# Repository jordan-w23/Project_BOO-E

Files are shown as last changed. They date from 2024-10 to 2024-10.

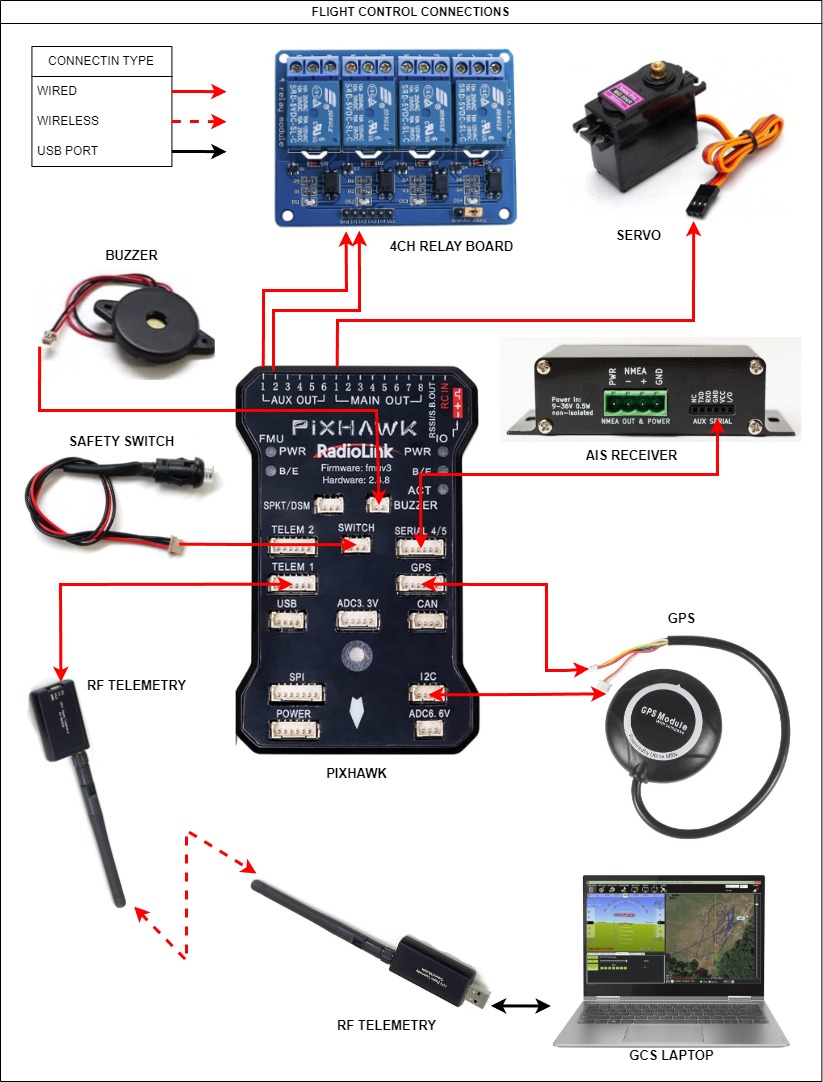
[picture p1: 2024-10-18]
BOO-E Diagrams/BOO-E overview-Signal and control flow.jpg

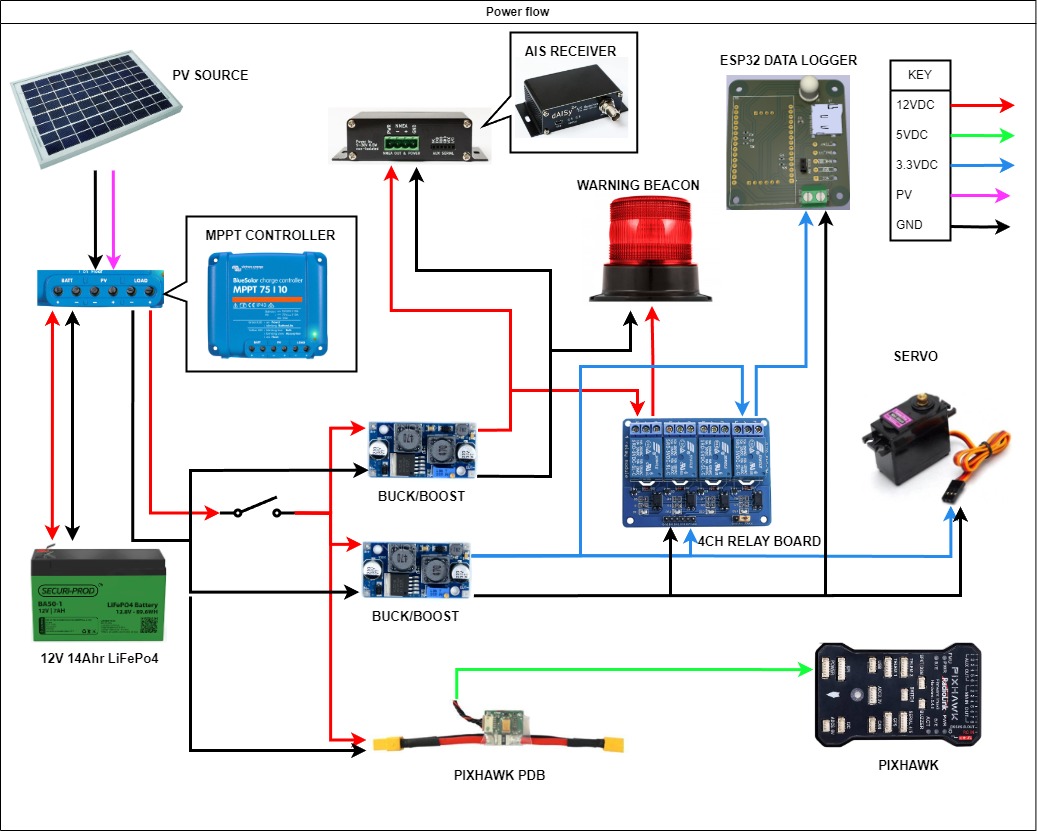
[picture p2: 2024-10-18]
BOO-E Diagrams/BOO-E overview-Power flow.jpg

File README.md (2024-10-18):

# Project_BOO-E
This is my Industrial designs project 3 for my 3rd year of Electrical Engineering studies. It is a proof of concept for a low cost autonomous vehicle using open-source recourses.
The system is broken down into 3 subsystems: Power, Navigation, Data logging
Ardupilot online forum is a key tool to use when setting up the flight controller and ground control station as most issues can be solved with a bit of research.

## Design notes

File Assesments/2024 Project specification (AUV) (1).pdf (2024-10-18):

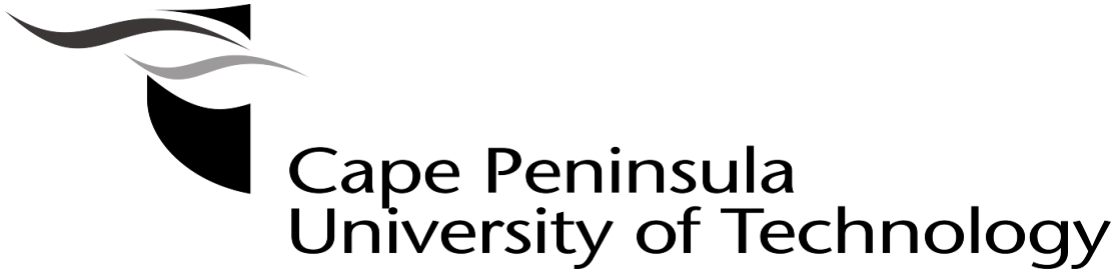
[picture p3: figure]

Title of project: Open-source based AUV

Problem Statement | The ocean is linked to weather, climate patterns, and all life on land. Thus, studying it helps researchers to predict trends and track the impact humans have made on the planet as well as monitor carbon emission levels. CTDs, moorings, gliders, and AUVs play a key role in data collection. However, these often require millions of rands to buy, thus excluding underfunded researchers from having access to ocean surveying and data collection instruments. Open-sourced designs allow for individuals to collaborate on projects, often resulting in higher quality, lower costs, and creates a positive space for growth and development within the project fields. Thus, there is a need for improvement and contributions towards open- source based AUV and glider projects.
Objectives | • Integrate various open-sourced components and software to develop a low cost AUV navigation system. • Integrate a source of regenerative energy and battery monitoring system. • Collect and log data from various sensors • Improve on electrical system to reduce power demand
Key Results | • Navigate via waypoint following • Long term deployment • Remote monitoring • Autonomous surfacing for recharging • Dive profile control
Impact/ Industry related significance | • Underfunded researchers have the means to conduct their own research at a fraction of the cost. • Open-source projects allows for goal specific modifications. • A positive contribution to the open-source community. • Accelerated innovation and development of more reliable, flexible and adaptable implementations

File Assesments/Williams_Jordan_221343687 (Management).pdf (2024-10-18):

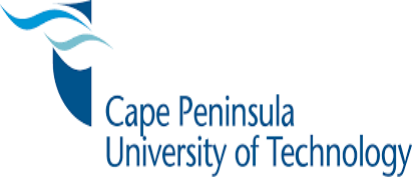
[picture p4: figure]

# Industrial Design Project 3 DES370S

## Project Title: Blue OpenOcean Explorer (BOO-E) Subtitle: Project Management Presentation

# Student Initial and Surname: JF Williams Student Number: 221343687 Lecturer: Dr M. Mnguni Date of Evaluation: 23/05/2024

23/05/2024 | 1

# Outline

## - Introduction • Proposed Plan • System overview • Benefits of Open

## -source Technology

- Budget Management • Risk Analysis • Time and Change Management • Quality Assurance • Economics Principles • Evaluation of Project Outcomes • Conclusion

23/05/2024

2

# Introduction

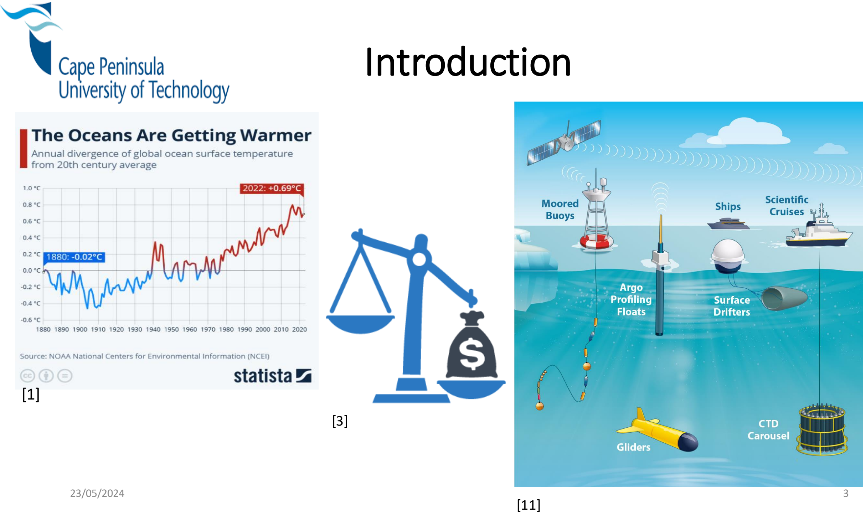
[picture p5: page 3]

[1]

[3]

[11]

# Proposed Plan Blue OpenOcean Explorer (BOO-E)

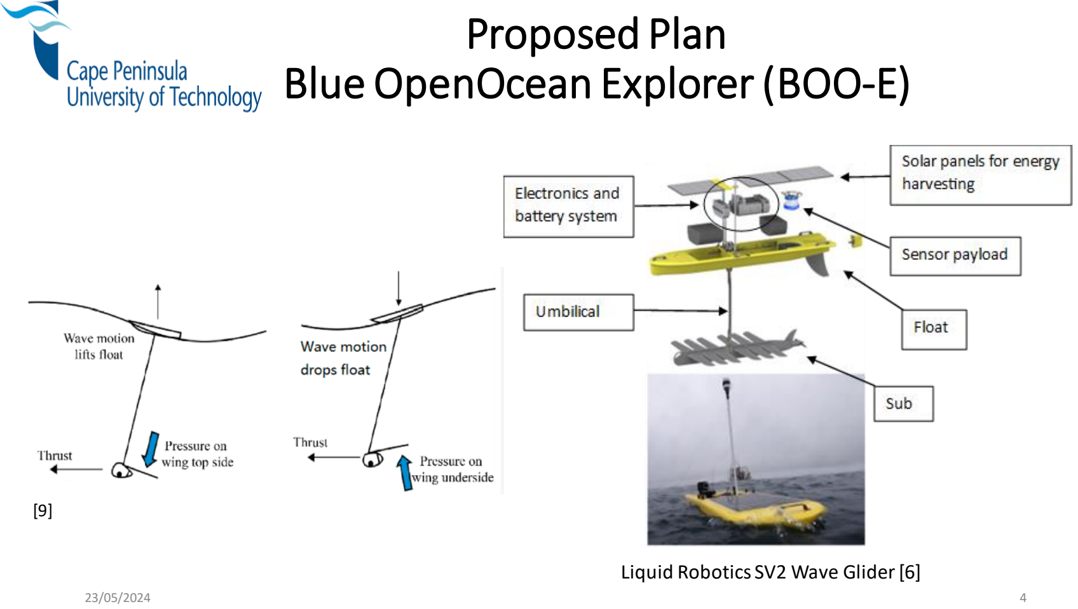
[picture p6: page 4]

### Liquid Robotics SV2 Wave Glider [6]

[9]

### Open-source based ASV project

### Navigation

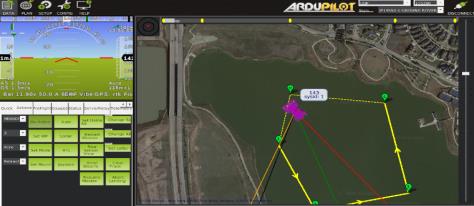
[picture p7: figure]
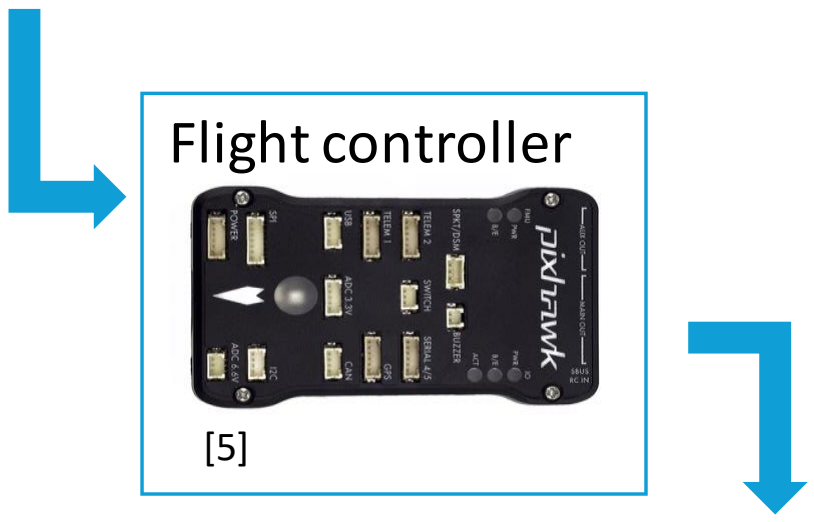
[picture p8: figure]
Flight controller

### Outputs: Rudder angle Thruster control Sail angle

### Inputs: GPS, Compass, IMU, Pilot control

### Data collection

### Sensors: Temp

### Salinity

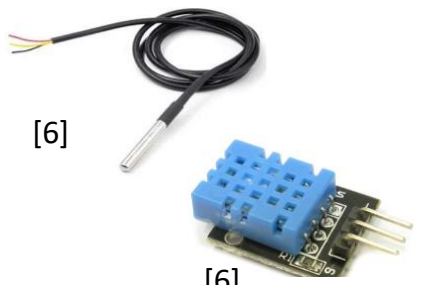
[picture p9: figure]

### Atmospheric data

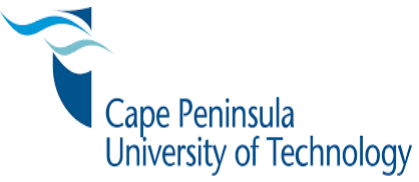
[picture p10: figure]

### Power management

### Harvesting: Solar and battery

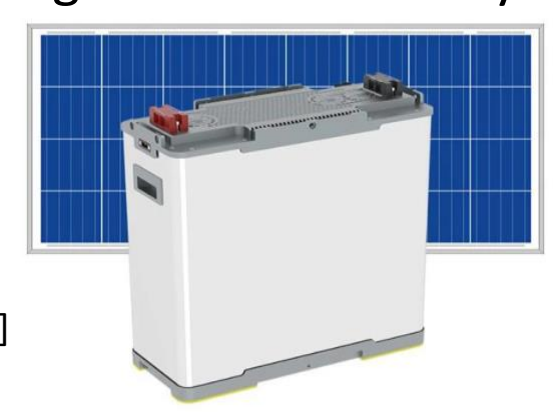
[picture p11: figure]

### storage

### Management: PDB's, DC-DC

# System overview

[5] [5]
[6]

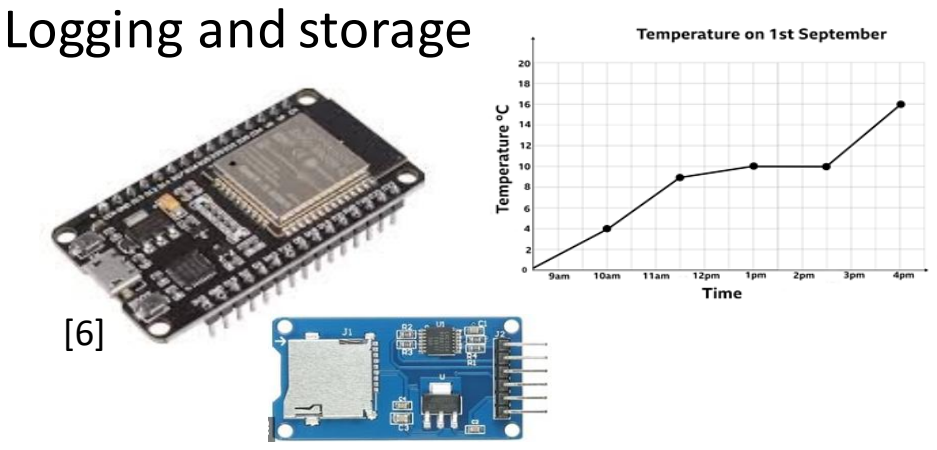
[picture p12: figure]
Logging and storage

[6]

[6]

[6]

# Benefits of Open-Source technology

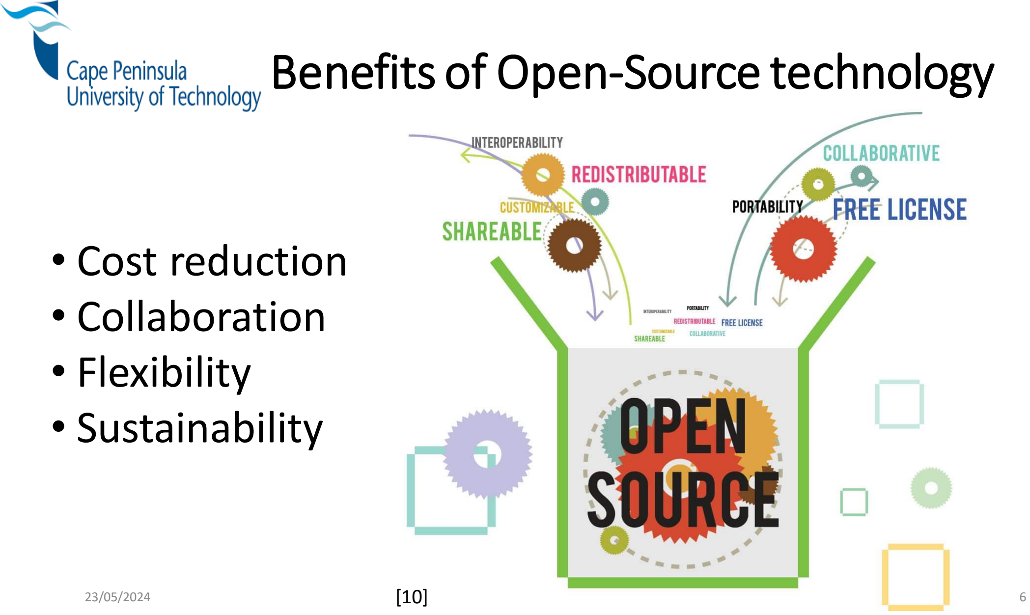
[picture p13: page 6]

# - Cost reduction - Collaboration - Flexibility - Sustainability

[10]

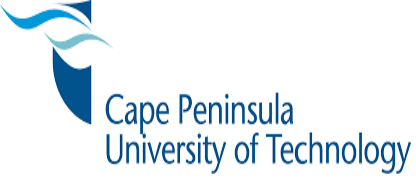
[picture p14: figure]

# Budget Management

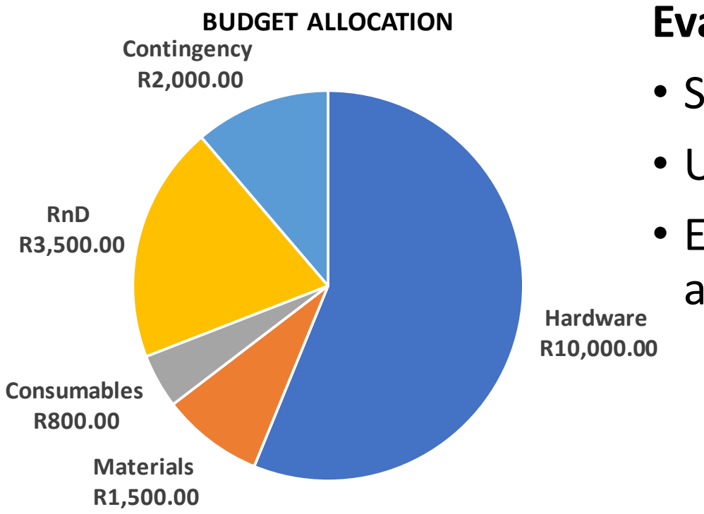
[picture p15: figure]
Hardware R10,000.00; Materials R1,500.00; Consumables R800.00; RnD R3,500.00; Contingency R2,000.00; BUDGET ALLOCATION

# Evaluation of Adherence to Budget - Securing sponsorships for companies (4, 7) - Use inhouse resources - Eliminate unnecessary expenses through risk assessment

### Budget total: R17,800.00

[4]

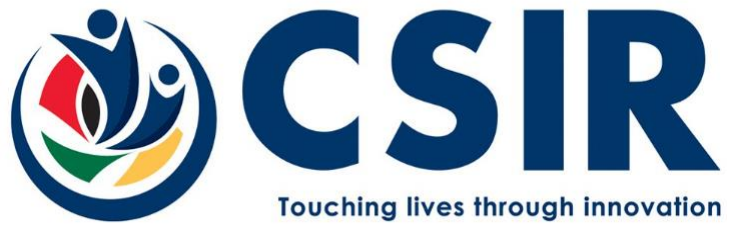
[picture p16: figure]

[7]

# Hardware cost breakdown

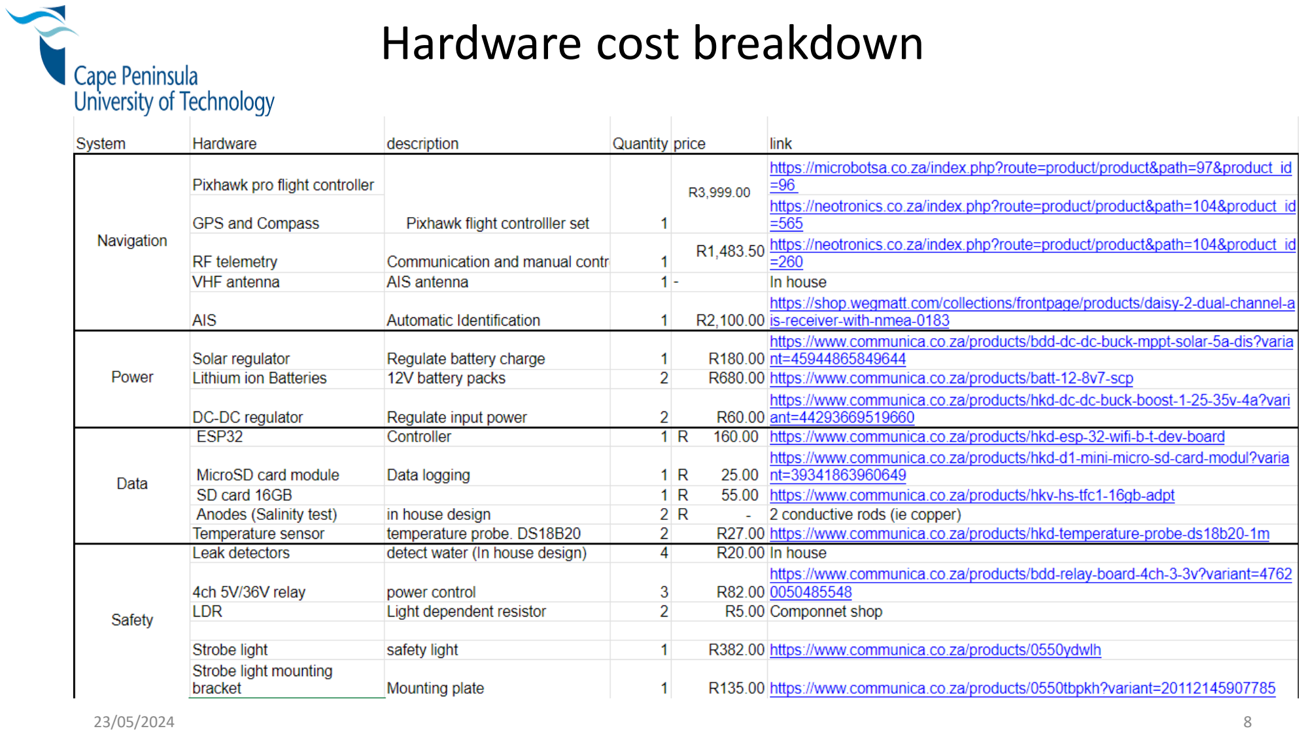
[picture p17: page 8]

# RISK ANALYSIS

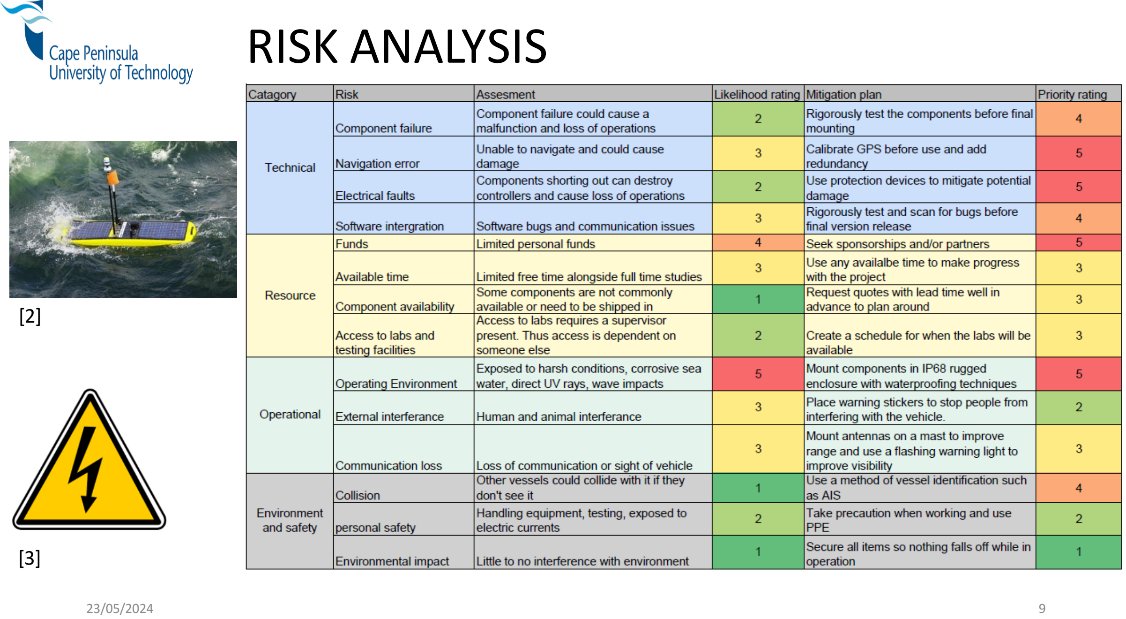
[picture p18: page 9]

[2]

[3]

# Time and Change Management

# - Monitoring Progress - Time Estimation for Each Task - Milestones and Deadlines

# Monitoring Progress

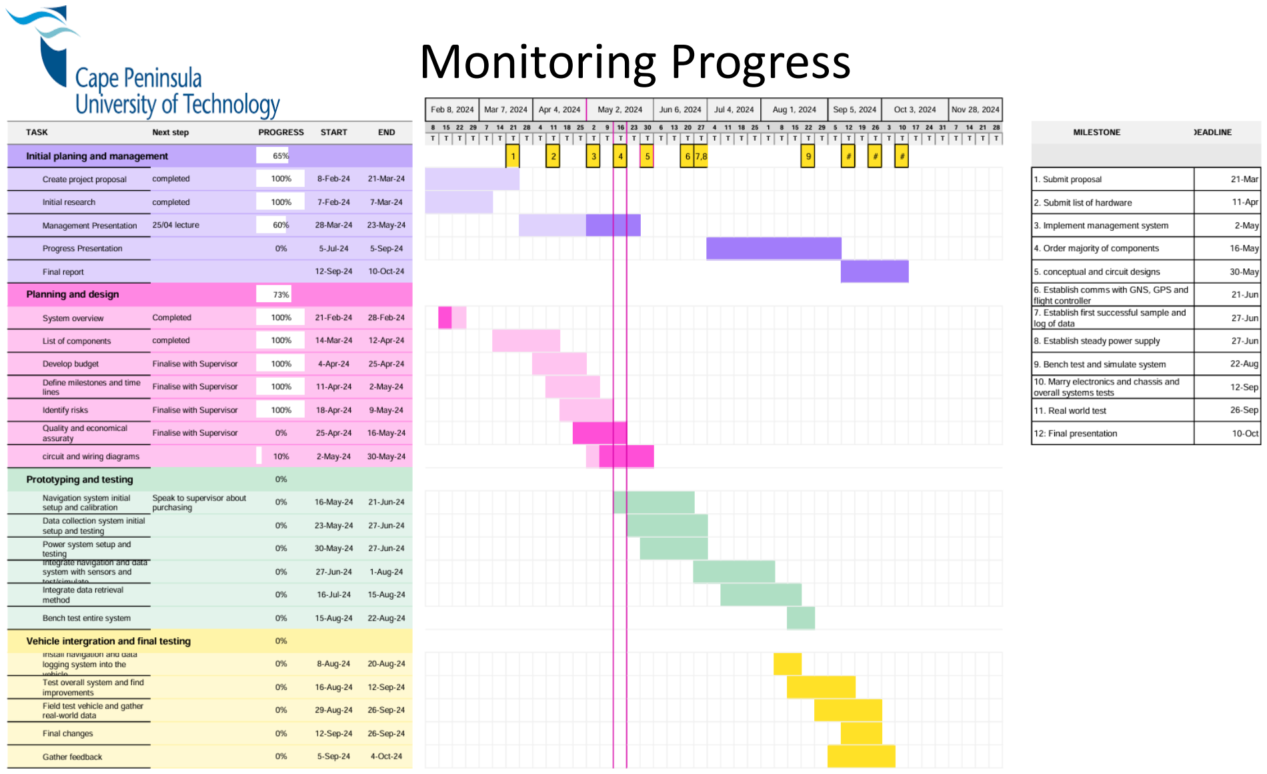
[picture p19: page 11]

# Time Estimation for Each Task

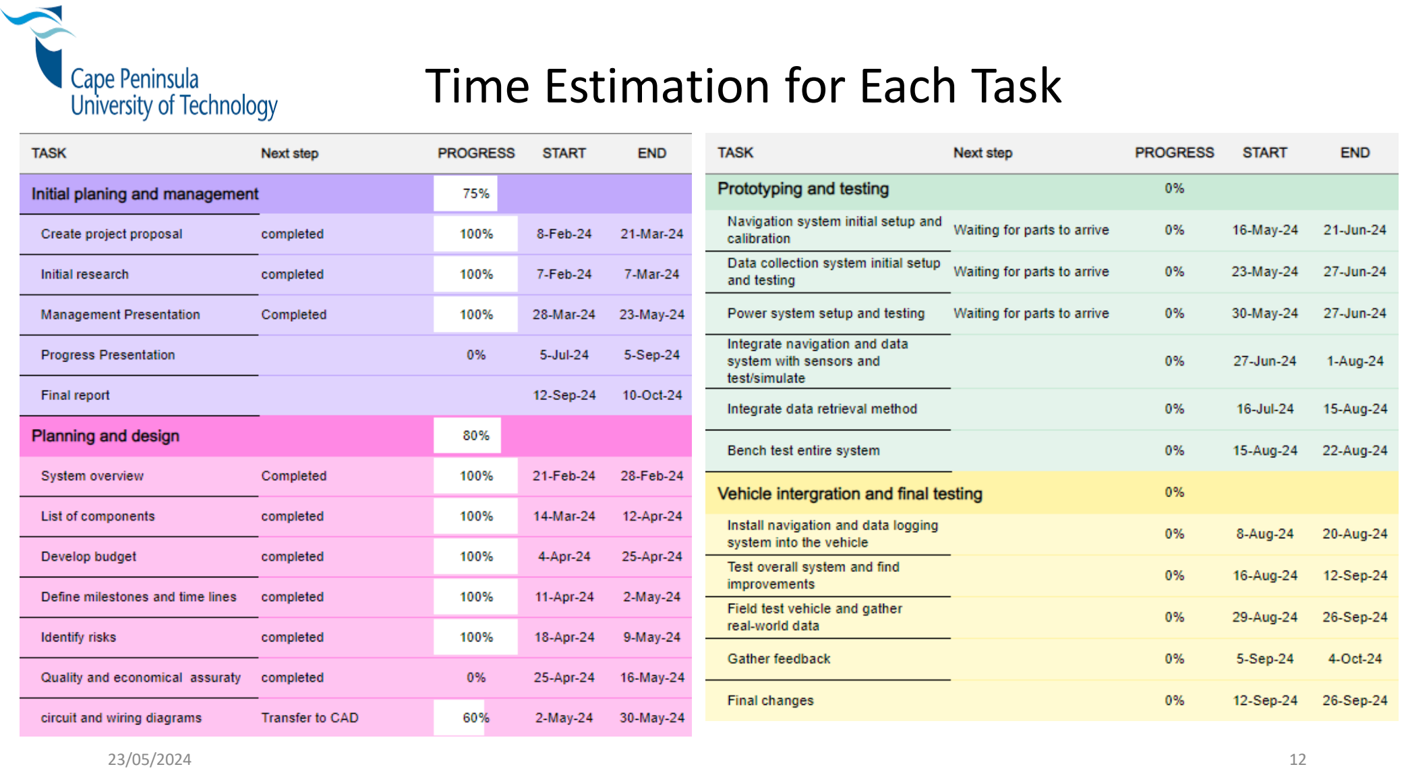
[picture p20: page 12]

# Milestones and deadlines

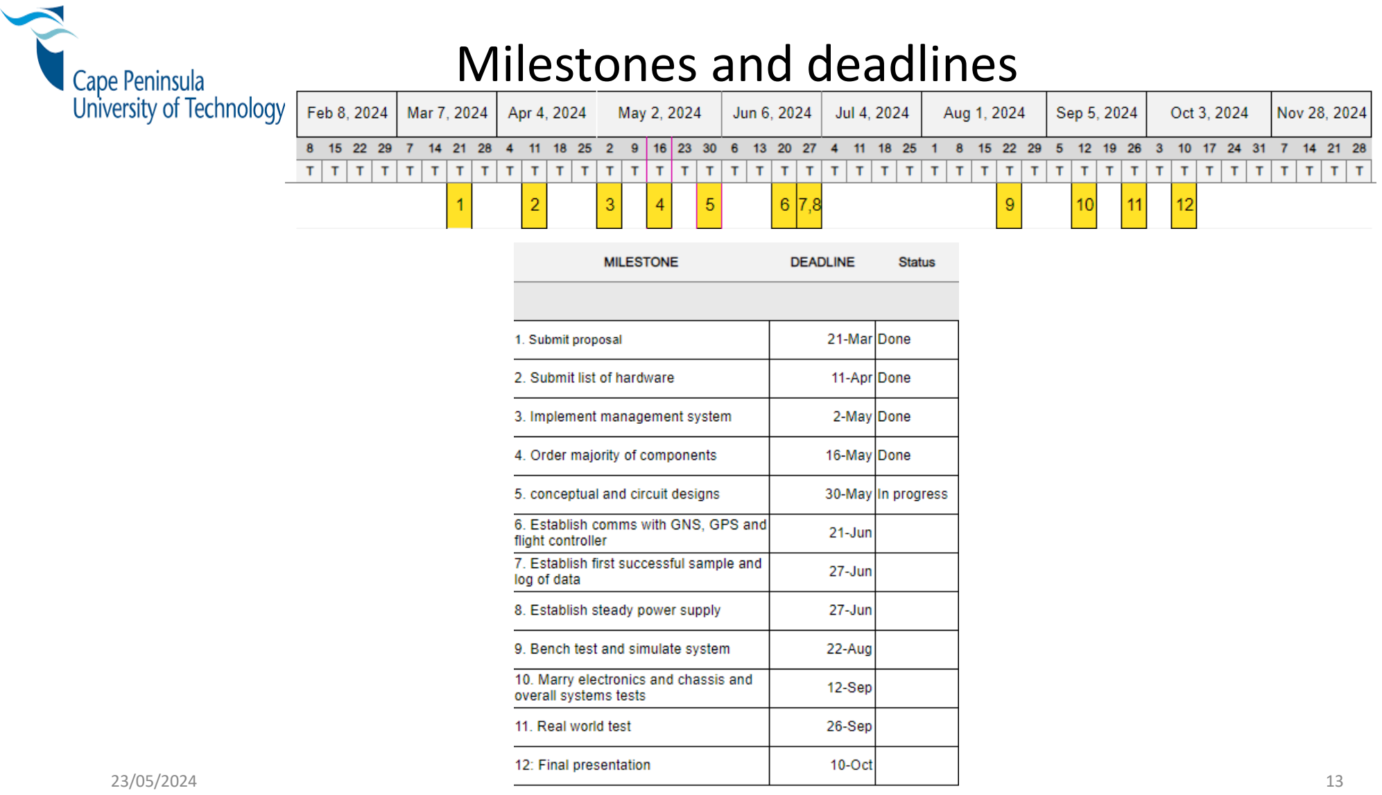
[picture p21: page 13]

# Quality Assurance

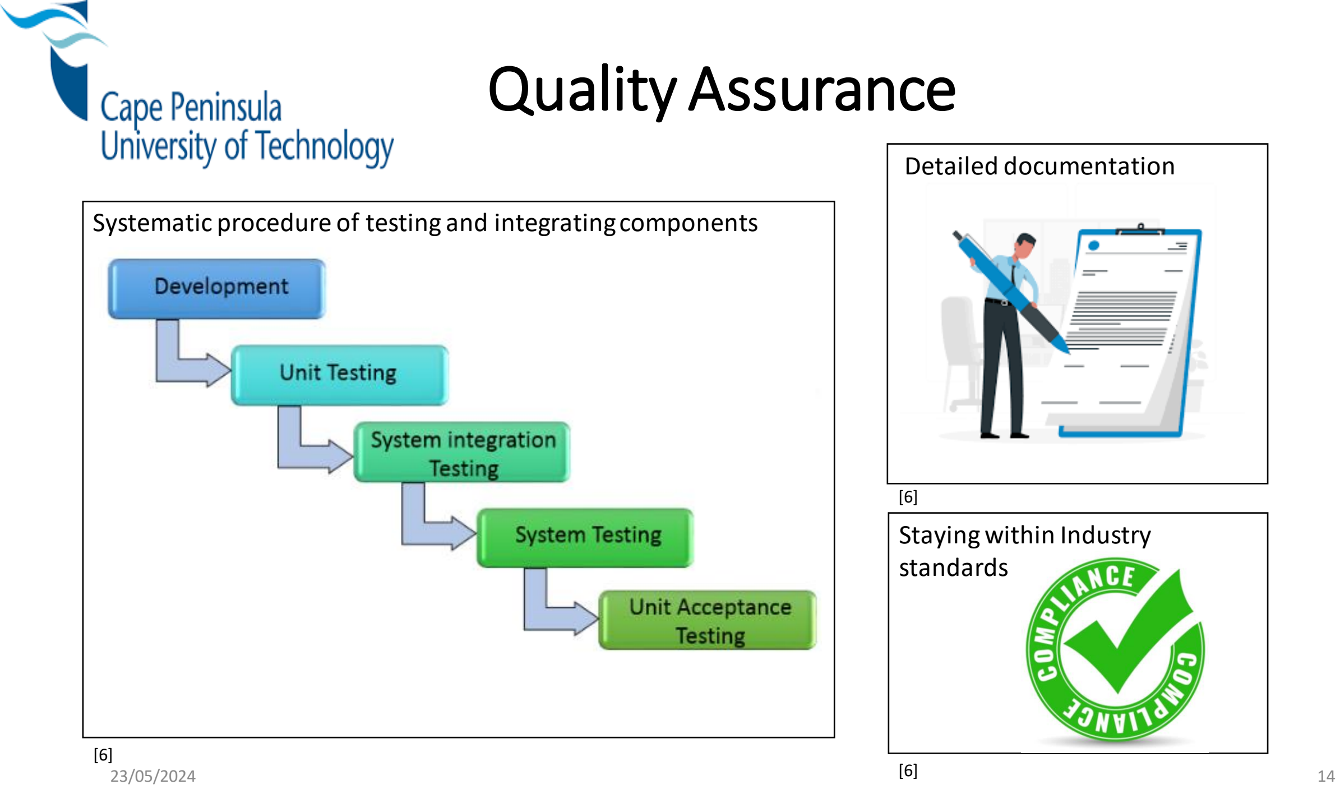
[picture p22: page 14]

### Systematic procedure of testing and integrating components

### Detailed documentation

### Staying within Industry standards

[6]
[6]

[6]

# Economics Principles

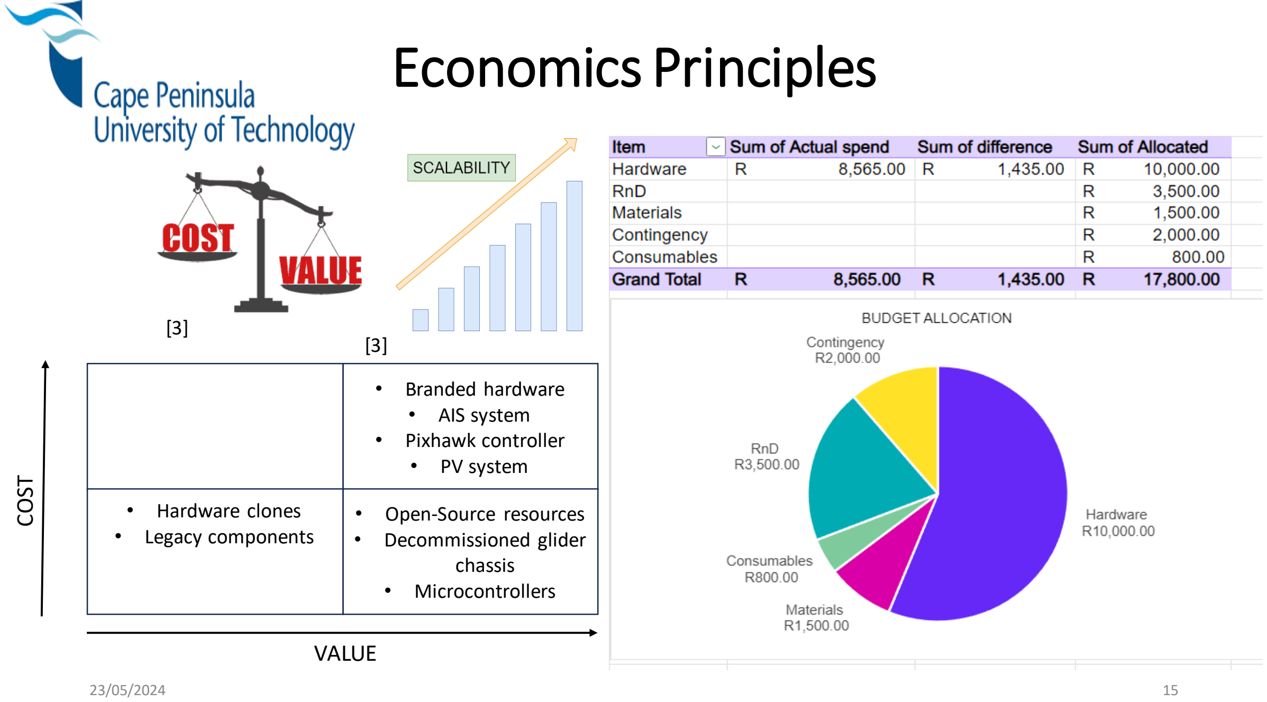
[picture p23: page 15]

| • Branded hardware • AIS system • Pixhawk controller • PV system
- Hardware clones • Legacy components | • Open-Source resources • Decommissioned glider chassis • Microcontrollers

### COST

### VALUE

[3]
[3]

# Expected Outcomes

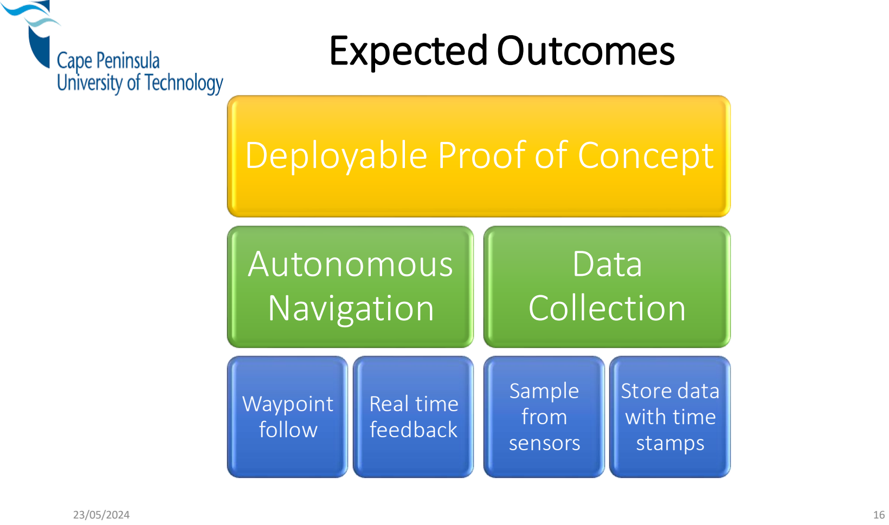
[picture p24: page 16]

# Deployable Proof of Concept

# Autonomous Navigation

## Waypoint follow

## Real time feedback

# Data Collection

## Sample from sensors

## Store data with time stamps

# Conclusion

# Proprietary < Open-Source

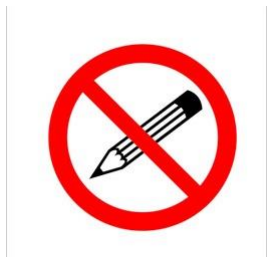
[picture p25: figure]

# - The more we understand the behaviour of our

oceans the better we can plan for our future.

[3] [3]

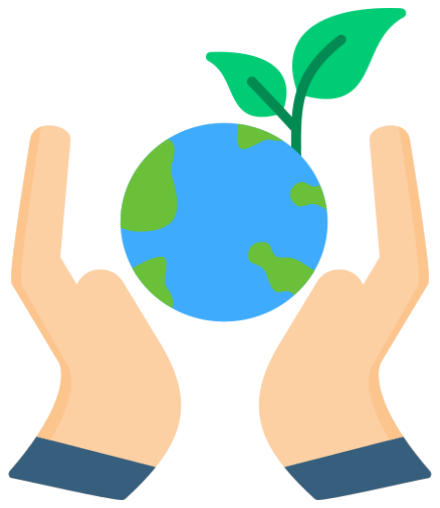
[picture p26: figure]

[3]

Thank you for you attention.

# Any questions?

## Contact details: Jordan Williams Cell: +27 78 136 7086 Email: 221343687@mycput.ac.za/ jordanwilliaams12@gmail.com


- [1] K. Buchholz, “Infographic: The Oceans Are Getting Warmer,” Statista Infographics, Jan. 15, 2021. https://www.statista.com/chart/19418/divergence-ofocean-temperatures-from-20th-century-average/ (https://www.statista.com/chart/19418/divergence-of-ocean-temperatures-from-20th-century-average/)
- [2] Sonardyne, “Redirect Notice,” Google.com, 2024. https://www.google.com/url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 AAAAAdAAAAABAE (https://www.google.com/url?psig=AOvVaw3xA_cL7y7ZwGIrjGevBaFK&cd=vfe&opi=89978449) (accessed May 21, 2024).
- [3] Clipart library , https://clipart-library.com/
- [4] Sea Technology Services, “Sea Technology Services,” Sea Technology Services. https://www.seatechnology.co.za/(accessed May 21, 2024).
- [5] Ardupilot, “Open Source Drone Software. Versatile, Trusted, Open. ArduPilot.,” ardupilot.org. https://ardupilot.org/
- [6] Communica south aftrica, “Communica South Africa,” Communica South Africa. https://www.communica.co.za/
- [7] “Council for Scientific and Industrial Research (CSIR) - Overview,” nationalgovernment.co.za. https://nationalgovernment.co.za/units/view/212/council-forscientific-and-industrial-research-csir (https://nationalgovernment.co.za/units/view/212/council-for-scientific-and-industrial-research-csir)
- [8] T. Morris et al., “Monitoring Boundary Currents Using Ocean Observing Infrastructure | Oceanography,” Frontiers in Ocean Observing: Documenting
Ecosystems, Understanding Environmental Changes, Forecasting Hazards, vol. 34, no. 4, Jan. 2022, doi: https://doi.org/10.5670/oceanog.2021..
- [9] X. Chen, M. Hong, S. Wu, K. Liu, and K. Mao, “Design of Wave Glider Optimal Parameters Suitable for the Northwest Pacific Ocean, the North Indian Ocean, and the South China Sea,” Journal of Marine Science and Engineering, vol. 9, no. 4, p. 408, Apr. 2021, doi: https://doi.org/10.3390/jmse9040408.
- [10] S. Kolhe, “The Benefits of Open Source Products,” opensourceforu, Sep. 20, 2015. https://www.opensourceforu.com/2015/09/the-benefits-of-open-source-products/?amp (accessed May 21, 2024).
- [11] Van Lancker and M. Baeye, “Wave Glider Monitoring of Sediment Transport and Dredge Plumes in a Shallow Marine Sandbank Environment,” PLOS ONE, vol. 10, no. 6, p. 5/15, Jun. 2015, doi: https://doi.org/10.1371/journal.pone.0128948.

# References

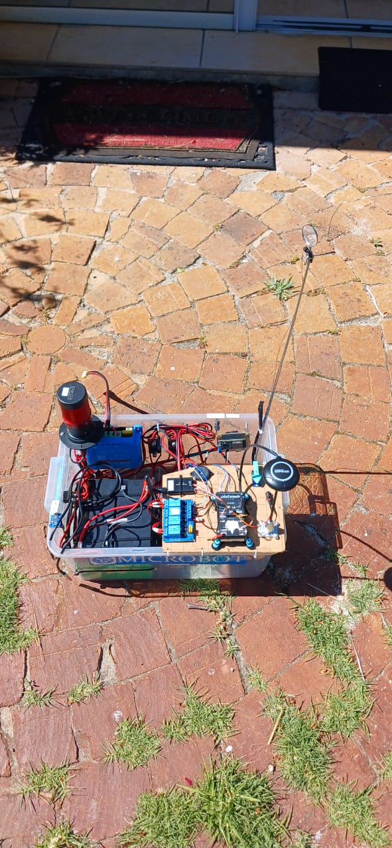
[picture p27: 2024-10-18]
Pictures/BOO-E/IMG-20241016-WA0004.jpg

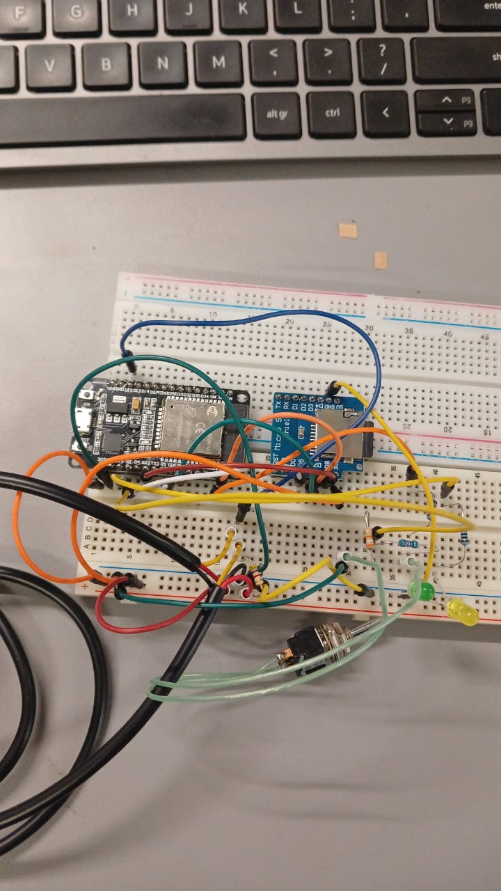
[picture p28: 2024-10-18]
Pictures/Data logger/IMG-20241016-WA0014.jpg

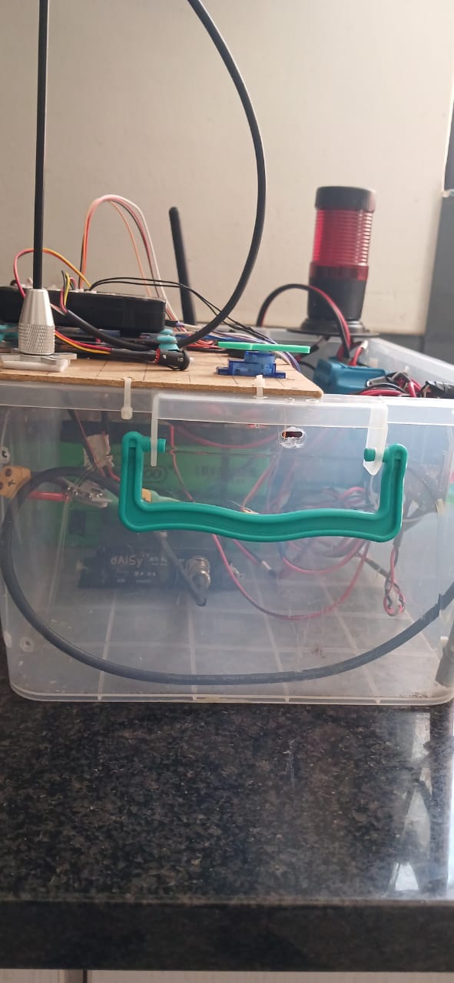
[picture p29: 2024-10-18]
Pictures/BOO-E/IMG-20241016-WA0055.jpg

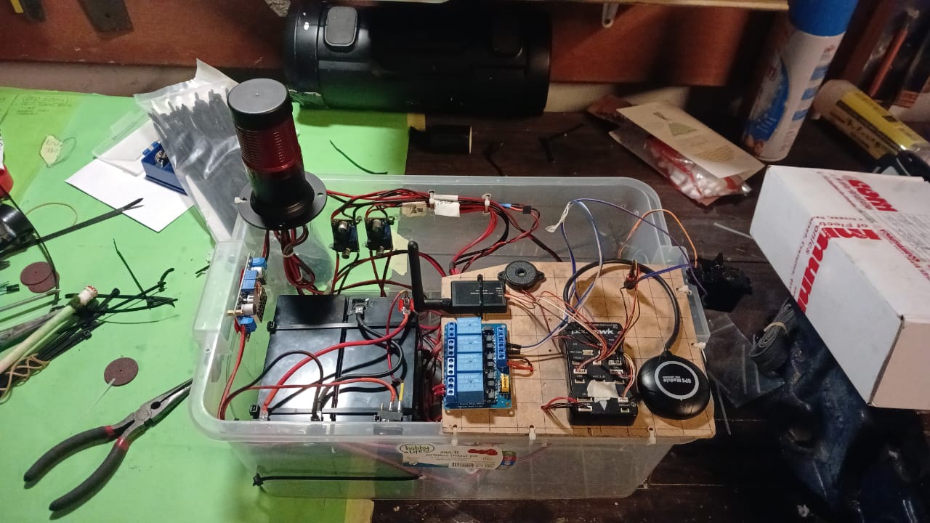
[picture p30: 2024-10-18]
Pictures/BOO-E/IMG-20241016-WA0012.jpg

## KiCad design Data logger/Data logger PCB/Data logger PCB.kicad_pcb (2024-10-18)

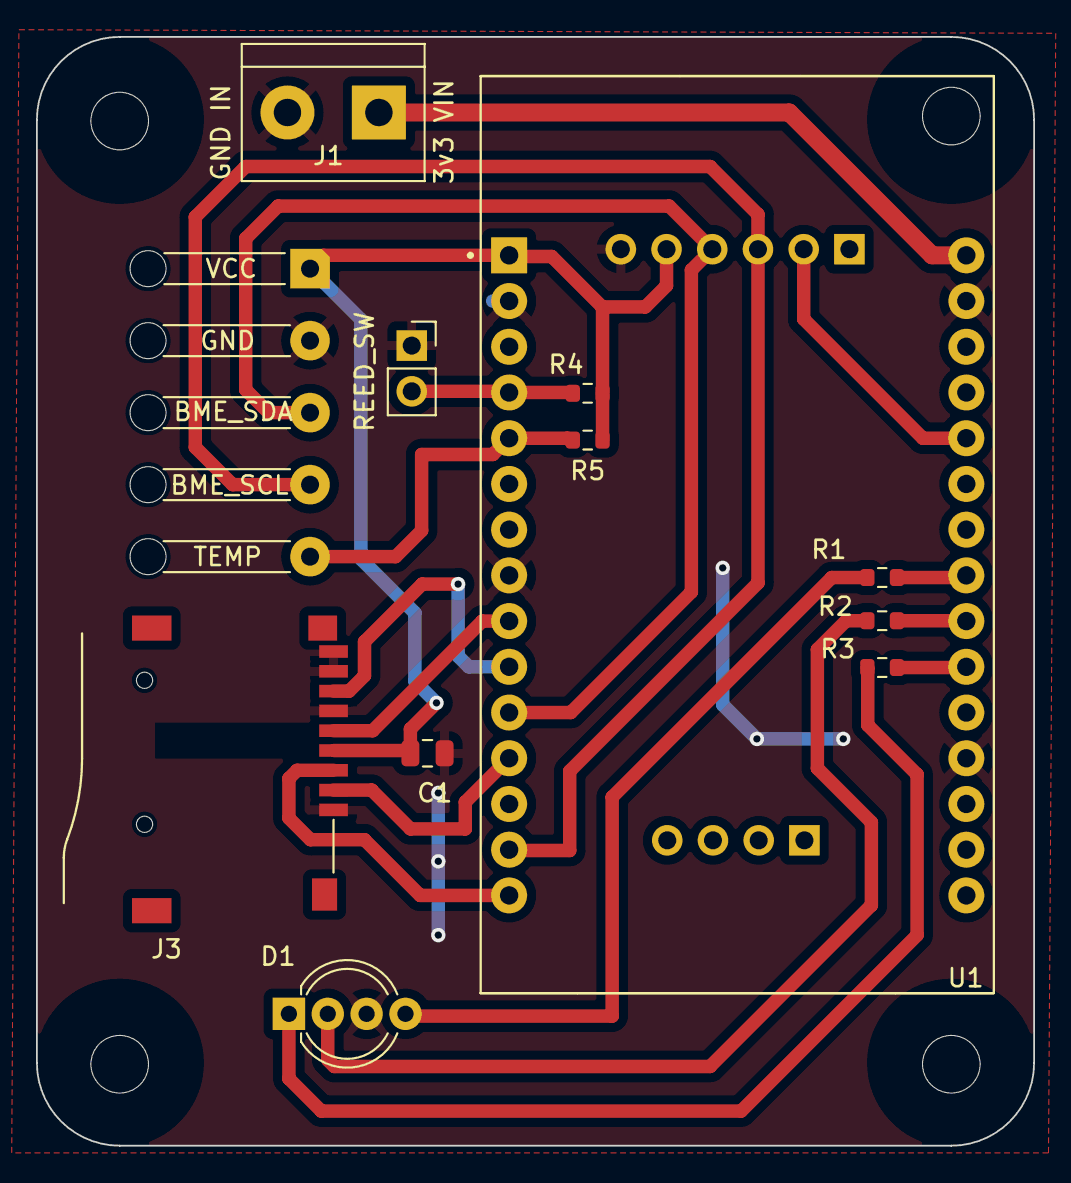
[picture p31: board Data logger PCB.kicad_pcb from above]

Board: 2 copper layers, 55.4 x 61.6 mm, 13 parts (1 on the bottom side), 18 nets.

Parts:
C1: 100nF; C_0805_2012Metric
D1: LED_RGAB; LED_D5.0mm-4_RGB_Wide_Pins
J1: Conn_01x02; TerminalBlock_bornier-2_P5.08mm
J2: Conn_2Rows-05Pins; SolderWire-0.15sqmm_1x05_P4mm_D0.5mm_OD1.5mm_Relief
J3: Micro_SD_Card; SUNTECH_ST-TF-003A
J5 (RTC): Conn_01x06_Socket; PinHeader_1x06_P2.54mm_Vertical
R1, R2, R3: 220; R_0603_1608Metric
R4: 10k; R_0603_1608Metric
R5: 4k7; R_0603_1608Metric
REED_SW: SW_Reed; PinSocket_1x02_P2.54mm_Vertical
U1: ESP32-DEVKIT-V1; MODULE_ESP32_DEVKIT_V1

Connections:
3v3 VIN: J1.1, U1.30 (VIN)
CLK: J3.5 (CLK), U1.9 (D18)
CS: J3.2 (DAT3/CD), U1.12 (RX0)
GND: C1.2, D1.3 (A), J1.2, J2.2, J3.1 (DAT2), J3.6 (VSS), J3.8 (DAT1), J3.9 (SHIELD), J5 (RTC).6, REED_SW.1, U1.2 (GND), U1.8 (D5), U1.19 (D34), U1.29 (GND)
Idle_status: R1.1, U1.23 (D25)
Log_status: R2.1, U1.22 (D33)
MISO: J3.7 (DAT0), U1.10 (D19)
MOSI: J3.3 (CMD), U1.15 (D23)
unnamed: D1.4 (BK), R1.2
unnamed: D1.2 (GK), R2.2
unnamed: D1.1 (RK), R3.2
REED_SW: R4.1, REED_SW.2, U1.4 (D2)
SCL: J2.4, J5 (RTC).3, U1.14 (D22)
SDA: J2.3, J5 (RTC).4, U1.11 (D21)
SQW*: J5 (RTC).2, U1.26 (D14)
TEMP: J2.5, R5.1, U1.5 (D4)
VCC: C1.1, J2.1, J3.4 (VDD), J5 (RTC).5, R4.2, R5.2, U1.1 (3V3)
Web_status: R3.1, U1.21 (D32)

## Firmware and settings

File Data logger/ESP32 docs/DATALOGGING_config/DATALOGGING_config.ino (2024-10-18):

/*TODO: COMMENTS
        

MILESTONES: SD card read
            Webserver active
            reed switch interupts
            data log
            CSV format
            Keep RTC time
            LED status indicators


  Basic description: Log and store time stamped data onto an SD card and using an esp to remotely access the data stored on the sd card. 
  Two different modes are made: Logging data, and initiate an asynchronous webserver to upload and dowload files from the SD card to your PC. 
    
 This code was developed by integrating pieces of code from various examples and projects made publically available. 
 The main contributers can be attributed to My Circuits 2022 and David Bird 2018.   
 
 Any redistribution or reproduction of any part or all of the contents in any form is prohibited other than the following:
 1. You may print or download to a local hard disk extracts for your personal and non-commercial use only.
 2. You may copy the content to individual third parties for their personal use, but only if you acknowledge the authors David Bird (2018), My Circuits (2022), Jordan Williams (2024) as the source of the material.
    
USE https://app.datawrapper.de/chart/klh7x/upload TO PLOT DATA IN A GRAPH BY SIMPLY UPLOADING A CSV.

*/
//Libraries for ESP32 WiFi
#include <WiFi.h>            
#include <ESP32WebServer.h> 
#include <ESPmDNS.h>
#include <esp_system.h>

//Includes headers of webserver and CSS style file
#include <CSS.h>  
#include <SPI.h>
#include <SD.h>
//#include <CSV_Parser.h>

//Headers for DS18B20 temp sensors
#include <OneWire.h>
#include <DallasTemperature.h>

//BME280 hum, pres, temp sensor
#include <Adafruit_BME280.h>  
#include <Wire.h>
#include <Adafruit_Sensor.h>

//Real Time Clock lib
#include <RTClib.h>
#include <EEPROM.h>
RTC_DS3231 rtc;

ESP32WebServer server(80);

#define servername "BOOEserver" //Define the name to your server...
#define SD_pin 3               //GPIO 16 in my case
#define w_mode 2                //GPIO 2 - Work Mode: logger or webserver
#define Log_status 32           //LED indicator ***GREEN***
#define Webserver_status 25     //LED indicator ***RED***
#define Idle_indicator 33       //LED indicator ***BLUE***
#define ONE_WIRE_BUS 4         //GPIO 4 data wire for Temp
#define EEPROM_SIZE 1           //Number of bytes to acces from EEPROM
#define RTC_ALARM_PIN 14

//variables to keep track of the timing of recent interrupts
const unsigned long debounceDelay = 900;  
volatile unsigned long lastInterruptTime = 0;
const char *username = "admin";
const char *password = "root";
volatile bool interruptTriggered = false; 
volatile bool waitingForSecondPress = false;
bool SD_present = false;                      //Controls if the SD card is present or not
bool Error_state = false;
bool powerOnReset = false;
int numberOfDevices;                          // Number of temperature devices found
float BME_pres, BME_temp, BME_hum;            //declare BME float variables
const int flagAddress = 0;    
int loggingDelay = 10;                      //******LOGGING DELAY HERE (in seconds)************

OneWire oneWire(ONE_WIRE_BUS);          //Setup a oneWire instance to communicate with any OneWire devices
DallasTemperature sensors(&oneWire);    //Pass our oneWire reference to Dallas Temperature.

DeviceAddress tempDeviceAddress;        // Variable to store a found device address
Adafruit_BME280 bme;

File logFile;
String logFileName;
char filename[30];

/****************************************************************
**************  INTERRUPT SERVICE ROUTINE  **********************
****************************************************************/
void IRAM_ATTR isr(){                   
  unsigned long currentTime = millis();
  if (currentTime - lastInterruptTime > debounceDelay){   //debounce function
    if (!waitingForSecondPress){
        interruptTriggered = true;
        waitingForSecondPress=true;
    } else {
        waitingForSecondPress=false;
    }
    lastInterruptTime = currentTime;
  }
} //isr end

/****************************************************************
***************  Create new ERROR log file  *********************
****************************************************************/
void logError(const String& errorMessage){
  File errorLogFile = SD.open("/error_log.txt", FILE_APPEND);
    if (errorLogFile) {
      DateTime now = rtc.now();  // Get the current timestamp
      char timestamp[20];
      sprintf(timestamp, "%04d-%02d-%02dT%02d:%02d:%02d", now.year(), now.month(), now.day(), now.hour(), now.minute(), now.second());    // Write timestamp and error message to the log file
      errorLogFile.print(timestamp);
      errorLogFile.print(": ");
      errorLogFile.println(errorMessage);
      errorLogFile.close();                                  // Close the log file
      Serial.println("Error logged: " + errorMessage);      // Debug output to the Serial Monitor
    } else {
        Serial.println("Failed to open error log file for writing");
    }
}

/****************************************************************
*****************  Create new file  *****************************
****************************************************************/
String createNewLogFile(){          //csv file name
  DateTime now = rtc.now();
  //char filename[30];
  sprintf(filename, "/%04d%02d%02d_data_test.csv", now.year(), now.month(), now.day(), now.hour(), now.minute());   //***********FILE NAME SET HERE**********
  // Create a new file
  logFile = SD.open(filename, FILE_APPEND);
  if (!logFile) {
    Serial.println("Creating new file");
    logFile = SD.open(filename, FILE_WRITE);
    logFile.println("Timestamp,TempC0,TempC1,BME_Temp,BME_Press,BME_Hum");
    logFile.flush();
  }
  logFile.close();
  return String(filename);
}

/****************************************************************
**************************  SETUP  ******************************
****************************************************************/
void setup(void){
  pinMode(RTC_ALARM_PIN , INPUT_PULLUP);
  pinMode(Log_status, OUTPUT);              //LED pin
  pinMode(Webserver_status, OUTPUT);        //LED pin
  pinMode(Idle_indicator, OUTPUT);        //LED pin
  pinMode(w_mode, INPUT_PULLUP);            //working mode
  attachInterrupt(w_mode, isr, FALLING);    //ISR interrupt GPIO pin

  Serial.begin(9600);
  delay(500);

    //Initialise RTC and set time to PC's time if not correct
  if (!rtc.begin()) {
    Serial.println("RTC module is NOT found");   //For debugging
    logError("RTC module is NOT found");
    Error_state = true;
    for (int i=0; i<5; i++){
      digitalWrite(Log_status, HIGH); //GREEN
      digitalWrite(Webserver_status, HIGH); //RED
      delay(500);
      digitalWrite(Log_status, LOW);
      digitalWrite(Webserver_status, LOW);
    }
    return;
  }
  else{
    Serial.println("RTC module is found");              //For debugging
    digitalWrite(Log_status, HIGH);  //GREEN
    delay(500);
    digitalWrite(Log_status, LOW);
    delay(250);
  }
  
  EEPROM.begin(1);                                    //initialise EEPROM                 
  //Serial.println(EEPROM.read(0));                     //Store flag in EEPROM address 0
  if (EEPROM.read(flagAddress) == 0){
    rtc.adjust(DateTime(F(__DATE__), F(__TIME__)));   //Adjust RTC time to PC's time
    EEPROM.write(flagAddress, 1);
    EEPROM.commit();
    Serial.println("Time has been updated");
  } else{
    Serial.println("Time is correct");
    digitalWrite(Log_status, HIGH);
    delay(500);
    digitalWrite(Log_status, LOW);
    delay(250);
  }

  rtc.disable32K();
  rtc.clearAlarm(1);
  rtc.clearAlarm(2);
  rtc.disableAlarm(2);
  rtc.writeSqwPinMode(DS3231_OFF);

  sensors.begin();                             // Start up oneWire & Dallas Temperature library
  numberOfDevices = sensors.getDeviceCount();   // locate devices on the bus
  Serial.print("Found ");
  Serial.print(numberOfDevices, DEC);
  Serial.println(" DS18B20 devices.");

  if (sensors.getDeviceCount() >= 2){
    digitalWrite(Log_status, HIGH);
    delay(500);
    digitalWrite(Log_status, LOW);
    delay(250);
  }

  if (sensors.getDeviceCount() < 2){
    Error_state = true;
    logError("Error with DS18B20 devices.");
    for (int i=0; i<5; i++){
      digitalWrite(Idle_indicator, HIGH); //BLUE
      digitalWrite(Webserver_status, HIGH); //RED
      delay(500);
      digitalWrite(Idle_indicator, LOW);
      digitalWrite(Webserver_status, LOW);
      }
  }
   


  //Initialise BME280
  if (!bme.begin(0x76)) {
    Serial.println("Could not find a valid BME280 sensor, check wiring!");    //For debugging
    logError("No BME280 found.");
    Error_state = true;
    for (int i=0; i<5; i++){
    digitalWrite(Idle_indicator, HIGH);
    digitalWrite(Webserver_status, HIGH);
    delay(500);
    digitalWrite(Idle_indicator, LOW);
    digitalWrite(Webserver_status, LOW);
    }
    return;
  }
  else{
    Serial.println("Valid BME280 sensor found");      //For debugging
    digitalWrite(Log_status, HIGH);
    delay(500);
    digitalWrite(Log_status, LOW);
    delay(250);
  }

  //see if the card is present and can be initialised.
  Serial.print(F("Initializing SD card..."));               //For debugging
  if (!SD.begin(SD_pin)) {
    Serial.println(F("ERROR: Card failed, or not present"));      //For debugging
    SD_present = false;
    Error_state = true;

    for (int i=0; i<5; i++){
    //digitalWrite(Idle_indicator, HIGH);
    digitalWrite(Webserver_status, HIGH); //RED
    //digitalWrite(Log_status, HIGH);
    delay(500);
    //digitalWrite(Idle_indicator, LOW);
    digitalWrite(Webserver_status, LOW);
    //digitalWrite(Log_status, LOW);
    }

    ESP.restart();
    return;
  }
  else{
    Serial.println("Card initialized.");        //For debugging
    SD_present = true;
    digitalWrite(Log_status, HIGH);
    delay(500);
    digitalWrite(Log_status, LOW);
    delay(250);
  }
  
  WiFi.softAP("BOO-E", "221343687");  //Network and password for the access point genereted by ESP32 http://BOOEserver.local/
  if (!MDNS.begin(servername)) {
    Serial.println("Error setting up MDNS responder!");    //For debugging
    logError("Error setting up MDNS responder!");
    digitalWrite(Webserver_status, HIGH);
    delay(2000);
    digitalWrite(Webserver_status, LOW);
    ESP.restart();
    }

  /*********  Server Commands  **********/
  server.on("/", SD_dir);
  server.on("/upload", File_Upload);
  server.on("/fupload", HTTP_POST, []() 
  { 
      server.send(200); 
    }, 
    handleFileUpload);

  server.begin();
  Serial.println("HTTP server started");        //For debugging

  Serial.println("Initialisation Finish");
  if (Error_state == false){
    logError("Successfull initialisation!");
    Serial.println("Initialisation Finish");
    for (int i =0; i < 2; i++){
      digitalWrite(Log_status, HIGH);
      digitalWrite(Webserver_status, HIGH);
      digitalWrite(Idle_indicator, HIGH);
      delay(500);
      digitalWrite(Log_status, LOW);
      digitalWrite(Webserver_status, LOW);
      digitalWrite(Idle_indicator, LOW);
      delay(250);
    }
  }
  if (Error_state == true){
    for(int i=0; 1< 10; i++){
      digitalWrite(Webserver_status, HIGH);
      delay(500);
      digitalWrite(Webserver_status, LOW);
      delay(500);
      Serial.println("REBOOT ESP32!!!");
    }
    ESP.restart();
  }

}//setup end

/****************************************************************
**************************  LOOP  *******************************
****************************************************************/
void loop(void){
  //Mode change detection  
  digitalWrite(Log_status, LOW);                                       //Set LED to LOW
  digitalWrite(Webserver_status, LOW);                                //Set LED to HIGH
  digitalWrite(Idle_indicator, HIGH);                                //Set LED to HIGH
  //rtc.clearAlarm(1);

  if (interruptTriggered){
    rtc.clearAlarm(1);
    digitalWrite(Log_status, LOW);                                       //Set LED to LOW
    digitalWrite(Webserver_status, HIGH);                                //Set LED to HIGH
    digitalWrite(Idle_indicator, LOW);
    interruptTriggered = false; //resets intertupt flag
    Serial.println("Button pressed, waiting for next press... http://BOOEserver.local/");         //For debugging
    WiFi.softAP("BOO-E", "12345678");
    delay(500);

    while(waitingForSecondPress){  
      server.handleClient();                                             //Listen for client connections
      delay(100);
    }
    Serial.println("Button pressed again, exiting wait loop...");        //For debugging
    logError("Mode cycled.");
    rtc.setAlarm1(rtc.now() + TimeSpan(30),DS3231_A1_Second);
    Serial.println("Logging starts in 30 seconds");
  }//interupt end

  /*esp_reset_reason_t resetReason = esp_reset_reason();
  if (resetReason == ESP_RST_POWERON) {
    // Set the flag for power-on reset
    Serial.println("Power on. Logging starts in 5 seconds");
    delay(5000);
    Data_Log();
  }*/

  if (digitalRead(RTC_ALARM_PIN) == LOW){
    Data_Log();                            //Call Data logging function
  }
}//loop end

/*********  FUNCTIONS  **********/

/****************************************************************
**************************  Data logging  ***********************
****************************************************************/
void Data_Log(){
  rtc.clearAlarm(1);
  DateTime now = rtc.now();
  //DateTime wakeUp;
  Serial.println();
  digitalWrite(Log_status, HIGH);         //Set LED to HIGH
  digitalWrite(Webserver_status, LOW);
  digitalWrite(Idle_indicator, LOW);
  sensors.requestTemperatures();                      //Call temp reading from DS18B20 sensors
  float TempC0 = sensors.getTempCByIndex(1);          
  float TempC1 = sensors.getTempCByIndex(0);
  float BME_Temp = bme.readTemperature();           //Call BME readings
  float BME_Press = bme.readPressure() / 100.0F;
  float BME_Hum = bme.readHumidity();
   
  // Open file for appending data
  logFileName = createNewLogFile();
  logFile = SD.open(filename, FILE_APPEND);
  if (!logFile) {
    logError("Failed to open file for data logging");     //log error
    Serial.println("Failed to open file for appending");
    digitalWrite(Log_status, HIGH);         //Set LED to HIGH
    digitalWrite(Webserver_status, HIGH);
    digitalWrite(Idle_indicator, HIGH);
    return;
  }
  Serial.println("File open");        //For debugging
  if (logFile.size() == 0) {
    logFile.println("Timestamp,TempC0,TempC1,BME_Temp,BME_Press,BME_Hum");   // If file is empty, write headers
  }
  
  char timestamp[20];                                     //create time stamp string YYYY-MM-DD HH:MM:SS
  sprintf(timestamp, "%04d-%02d-%02dT%02d:%02d:%02d", 
          now.year(), now.month(), now.day(), 
          now.hour(), now.minute(), now.second());
  //Create csv string format
  logFile.print(timestamp);
  logFile.print(",");
  logFile.print(TempC0);
  logFile.print(",");
  logFile.print(TempC1);
  logFile.print(",");
  logFile.print(BME_Temp);
  logFile.print(",");
  logFile.print(BME_Press);
  logFile.print(",");
  logFile.println(BME_Hum);
  logFile.close(); // Close the current file
 
  //For Debugging
  Serial.print(timestamp);
  Serial.print(",");
  Serial.print(TempC0);
  Serial.print(",");
  Serial.print(TempC1);
  Serial.print(",");
  Serial.print(BME_Temp);
  Serial.print(",");
  Serial.print(BME_Press);
  Serial.print(",");
  Serial.println(BME_Hum);

  Serial.println("Data written to file");   //For Debugging
  Serial.println();

  File dataF = SD.open("/CONFIG.TXT");
  String L_delay =dataF.readStringUntil('\n');
  L_delay.replace("Sampling rate (sec): ","");
  L_delay.replace("\"","");
  L_delay.replace("\n","");
  loggingDelay = L_delay.toInt();
  dataF.close();
  
  if (loggingDelay <= 60){
    rtc.setAlarm1(rtc.now() + TimeSpan(loggingDelay),DS3231_A1_Second);   //RTC logging alarm SECONDS
  }
  if( loggingDelay > 60 && loggingDelay <= 3600){
    rtc.setAlarm1(rtc.now() + TimeSpan(loggingDelay/60),DS3231_A1_Minute);   //RTC logging alarm MINUTE
  }
  if( loggingDelay > 3600 && loggingDelay <= 86400){
    rtc.setAlarm1(rtc.now() + TimeSpan(loggingDelay/3600),DS3231_A1_Hour);   //RTC logging alarm hour
  }
  
 /* if(L_delay.indexOf("(sec)") >= 0){
    L_delay.replace("Sampling rate (sec): ","");
    L_delay.replace("\"","");
    L_delay.replace("\n","");
    loggingDelay = L_delay.toInt();
    rtc.setAlarm1(rtc.now() + TimeSpan(loggingDelay),DS3231_A1_Second);   //RTC logging alarm
  }
  if(L_delay.indexOf("(min)") >= 0){
    L_delay.replace("Sampling rate (min): ","");
    L_delay.replace("\"","");
    L_delay.replace("\n","");
    loggingDelay = L_delay.toInt();
    rtc.setAlarm1(rtc.now() + TimeSpan(loggingDelay),DS3231_A1_Minute);   //RTC logging alarm
  }*/
  
  delay(100);
  Serial.print(loggingDelay);   //For Debugging
  Serial.println(" second logging delay");
}//Data logging end

/****************************************************************
**********  WEBSERVER ACTION (DO NOT EDIT THIS SECTION)  ********
****************************************************************/
//Init=ial page of the server web, list directory and give you the chance of deleting and uploading
void SD_dir() {
  if(!server.authenticate(username, password)){
    return server.requestAuthentication();
  }
  if (SD_present) 
  {
    //Action acording to post, dowload or delete, by MC 2022
    if (server.args() > 0)  //Arguments were received, ignored if there are not arguments
    {
      Serial.println(server.arg(0));

      String Order = server.arg(0);
      Serial.println(Order);

      if (Order.indexOf("download_") >= 0) 
      {
        Order.remove(0, 9);
        SD_file_download(Order);
        Serial.println(Order);
      }

      if ((server.arg(0)).indexOf("delete_") >= 0) 
      {
        Order.remove(0, 7);
        SD_file_delete(Order);
        Serial.println(Order);
      }
    }

    File root = SD.open("/");
    if (root) 
    {
      root.rewindDirectory();
      SendHTML_Header();
      webpage += F("<table align='center'>");
      webpage += F("<tr><th>Name/Type</th><th style='width:20%'>Type File/Dir</th><th>File Size</th></tr>");
      printDirectory("/", 0);
      webpage += F("</table>");
      SendHTML_Content();
      root.close();
    } 
    else {
      SendHTML_Header();
      webpage += F("<h3>No Files Found</h3>");
    }
    append_page_footer();
    SendHTML_Content();
    SendHTML_Stop();  //Stop is needed because no content length was sent
  } 
  else ReportSDNotPresent();
}

//Upload a file to the SD
void File_Upload() {
  append_page_header();
  webpage += F("<h3>Select File to Upload</h3>");
  webpage += F("<FORM action='/fupload' method='post' enctype='multipart/form-data'>");
  webpage += F("<input class='buttons' style='width:25%' type='file' name='fupload' id = 'fupload' value=''>");
  webpage += F("<button class='buttons' style='width:10%' type='submit'>Upload File</button><br><br>");
  webpage += F("<a href='/'>[Back]</a><br><br>");
  append_page_footer();
  server.send(200, "text/html", webpage);
}

//Prints the directory, it is called in void SD_dir()
void printDirectory(const char* dirname, uint8_t levels) {

  File root = SD.open(dirname);

  if (!root) 
  {
    return;
  }
  if (!root.isDirectory()) 
  {
    return;
  }
  File file = root.openNextFile();

  int i = 0;
  while (file) 
  {
    if (webpage.length() > 1000) 
    {
      SendHTML_Content();
    }
    if (file.isDirectory()) 
    {
      webpage += "<tr><td>" + String(file.isDirectory() ? "Dir" : "File") + "</td><td>" + String(file.name()) + "</td><td></td></tr>";
      printDirectory(file.name(), levels - 1);
    } 
    else 
    {
      webpage += "<tr><td>" + String(file.name()) + "</td>";
      webpage += "<td>" + String(file.isDirectory() ? "Dir" : "File") + "</td>";
      int bytes = file.size();
      String fsize = "";
      if (bytes < 1024) fsize = String(bytes) + " B";
      else if (bytes < (1024 * 1024)) fsize = String(bytes / 1024.0, 3) + " KB";
      else if (bytes < (1024 * 1024 * 1024)) fsize = String(bytes / 1024.0 / 1024.0, 3) + " MB";
      else fsize = String(bytes / 1024.0 / 1024.0 / 1024.0, 3) + " GB";
      webpage += "<td>" + fsize + "</td>";
      webpage += "<td>";
      webpage += F("<FORM action='/' method='post'>");
      webpage += F("<button type='submit' name='download'");
      webpage += F("' value='");
      webpage += "download_" + String(file.name());
      webpage += F("'>Download</button>");
      webpage += "</td>";
      webpage += "<td>";
      webpage += F("<FORM action='/' method='post'>");
      webpage += F("<button type='submit' name='delete'");
      webpage += F("' value='");
      webpage += "delete_" + String(file.name());
      webpage += F("'>Delete</button>");
      webpage += "</td>";
      webpage += "</tr>";
    }
    file = root.openNextFile();
    i++;
  }
  file.close();
}

//Download a file from the SD, it is called in void SD_dir()
void SD_file_download(String filename) {
  if (SD_present) {
    File download = SD.open("/" + filename);
    if (download) 
    {
      server.sendHeader("Content-Type", "text/text");
      server.sendHeader("Content-Disposition", "attachment; filename=" + filename);
      server.sendHeader("Connection", "close");
      server.streamFile(download, "application/octet-stream");
      download.close();
    } 
    else ReportFileNotPresent("download");
  } 
  else ReportSDNotPresent();
}
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

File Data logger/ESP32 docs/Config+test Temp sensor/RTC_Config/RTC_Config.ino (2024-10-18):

#include <RTClib.h>
RTC_DS3231 rtc;

#define EEPROM_SIZE 1           
#include <EEPROM.h>

void setup() {
  // put your setup code here, to run once:
  Serial.begin(9600);
  EEPROM.begin(1);
  if (!rtc.begin()) {
    Serial.println("RTC module is NOT found");   //For debugging
    return;
  }
  Serial.println("RTC module is found");
  rtc.adjust(DateTime(F(__DATE__), F(__TIME__)));   //Adjust RTC time to PC's time
  EEPROM.write(0, 0);
  EEPROM.commit();
  Serial.println(EEPROM.read(0));
  }


void loop() {
  // put your main code here, to run repeatedly:
  DateTime now = rtc.now();
  char timestamp[20];                                     //create time stamp string YYYY-MM-DD HH:MM:SS
  sprintf(timestamp, "%04d-%02d-%02d %02d:%02d:%02d", 
          now.year(), now.month(), now.day(), 
          now.hour(), now.minute(), now.second());
  Serial.println(timestamp);
  delay(5000);        

}
